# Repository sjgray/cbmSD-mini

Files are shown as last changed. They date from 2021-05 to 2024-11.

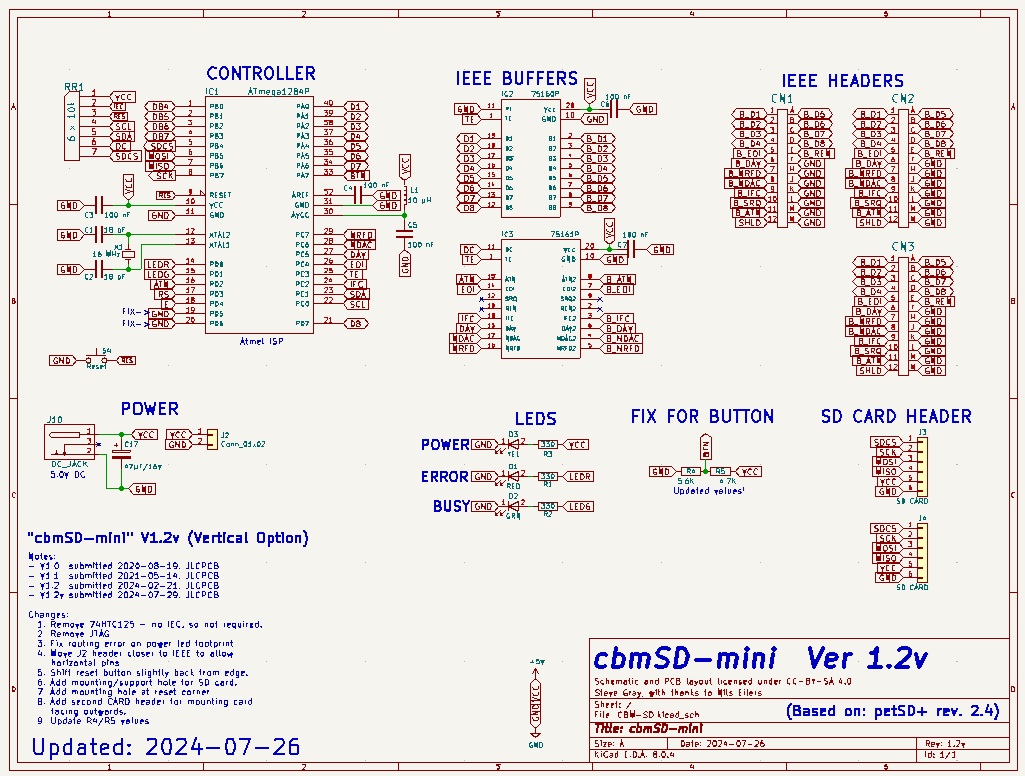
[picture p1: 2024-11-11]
v1.2v/Pics/schematic.jpg

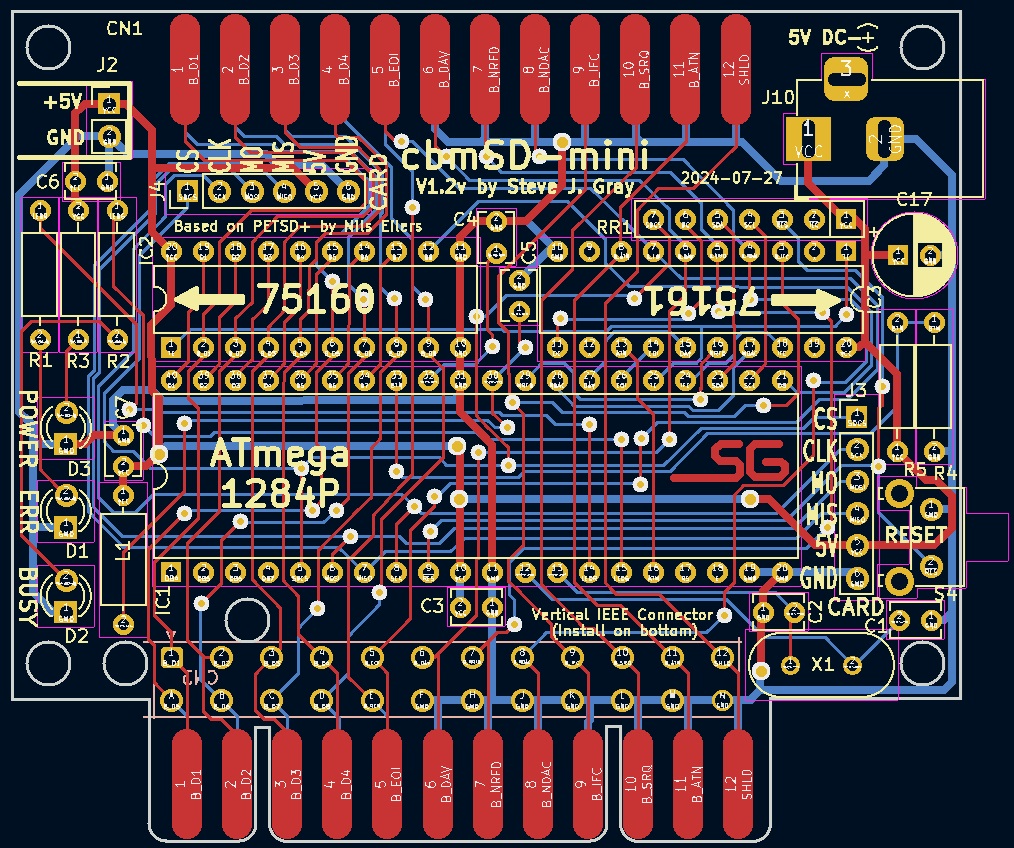
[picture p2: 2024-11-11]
v1.2v/Pics/routing.jpg

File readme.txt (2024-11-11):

cbmSD-mini - SD Card Drive for Commodore Computers with IEEE
============================================================

The goal of this project is to create a free open-source
disk drive solution that is easy to build using all
thru-hole parts plus the use of a common inexpensive SD
card module.

This device is based on the petSD+ v2.4 from Nils Eilers.
I have removed all the non-essential features and have
designed it to plug directly into the back of the computer.
No IEEE cables are required. However, it also has a
pass-thru to add additional drives if you need.

You will need a simple cassette port power plug or you can
power it with a standard 5V adapter with barrel jack.

Features
--------

- Direct plug into IEEE port
- Pass-thru IEEE port
- Power, Busy and Error lights
- SD module can be mounted on header or extended via wires.
- Reset switch.
- Two Power headers for input or output (to additional
  cbmSD-mini units).
- Mounting holes for future 3D case.

Project Page
------------

http://www.cbmsteve.ca/cbmsd/index.html

Status
------

 cbmSD      1.0:  Was the first version for prototyping. It supported IEEE and IEC
                  like the PETSD+. 
 cbmSD-mini 1.1:  Removed IEC port and AUX header. IEEE only for PET/CBM users.
                  Gerbers sent to JLCPCB on 2021-05-14.
 cbmSD-mini 1.2:  Fix trace short on LED. Remove 74125 which is not reqired
                  for IEEE. Update design for Kicad7.
                  Gerbers sent to JLCPCB on 2024-02-21.
 cmmSD-mini 1.2v  Add vertical mounting option.
                  Gerbers sent to JLCPCB on 2024-07-30.

Steve
2024-11-11

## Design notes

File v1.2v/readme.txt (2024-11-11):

cbmSD-mini - SD Card Drive for Commodore Computers with IEEE
============================================================

**NEW** Webpage: http://cbmsteve.ca/cbmsd/index.html

The goal of this project is to create a free open-source
disk drive solution that is easy to build using all
thru-hole parts plus the use of a common inexpensive SD
card module.

This device is based on the petSD+ v2.4 from Nils Eilers.
I have removed all the non-essential features and have
designed it to plug directly into the back of the computer.
No IEEE cables are required. However, it also has a
pass-thru to add additional drives if you need.

You will need a simple cassette port power plug or you can
power it with a standard 5V adapter with barrel jack.

Features
--------

- Direct plug into IEEE port
- Pass-thru IEEE port
- Power, Busy and Error lights
- SD module can be mounted on header or extended via wires.
- Reset switch.
- Two Power headers for input or output (to additional
  cbmSD-mini units.
- Mounting holes for future 3D case.
- Vertical mounting option

Status
------

 V1.0: Was the first version for prototyping. It had a few errors.       
 V1.1: Removed IEC port and AUX header. IEEE only for PET/CBM users.
       Gerbers sent to JLCPCB on 2021-05-14.
 V1.2: Fix trace short on LED. Remove 74125 which is not required
       for IEEE. Update design for Kicad7.
 V1.2v: No fundamental changes. Moved some parts to make way for
        vertical mounting option.

Steve
2024-02-21

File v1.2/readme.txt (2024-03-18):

cbmSD-mini - SD Card Drive for Commodore Computers with IEEE
============================================================

Webpage: http://www.6502.org/users/sjgray/projects/cbmsd/index.html

The goal of this project is to create a free open-source
disk drive solution that is easy to build using all
thru-hole parts plus the use of a common inexpensive SD
card module.

This device is based on the petSD+ v2.4 from Nils Eilers.
I have removed all the non-essential features and have
designed it to plug directly into the back of the computer.
No IEEE cables are required. However, it also has a
pass-thru to add additional drives if you need.

You will need a simple cassette port power plug or you can
power it with a standard 5V adapter with barrel jack.

Features
--------

- Direct plug into IEEE port
- Pass-thru IEEE port
- Power, Busy and Error lights
- SD module can be mounted on header or extended via wires.
- Reset switch.
- Two Power headers for input or output (to additional
  cbmSD-mini units.
- Mounting holes for future 3D case.

Status
------

 V1.0: Was the first version for prototyping. It had a few errors.       

 V1.1: Removed IEC port and AUX header. IEEE only for PET/CBM users.
       Gerbers sent to JLCPCB on 2021-05-14.
       Board built and verified working with one small fix.

 V1.2: Fix trace short on LED. Remove 74125 which is not reqired
       for IEEE. Update design for Kicad7.
       Gerbers sent to JLCPCB on 2024-02-21.
       Board built and verified working 2024-03-17

Steve
2024-03-18

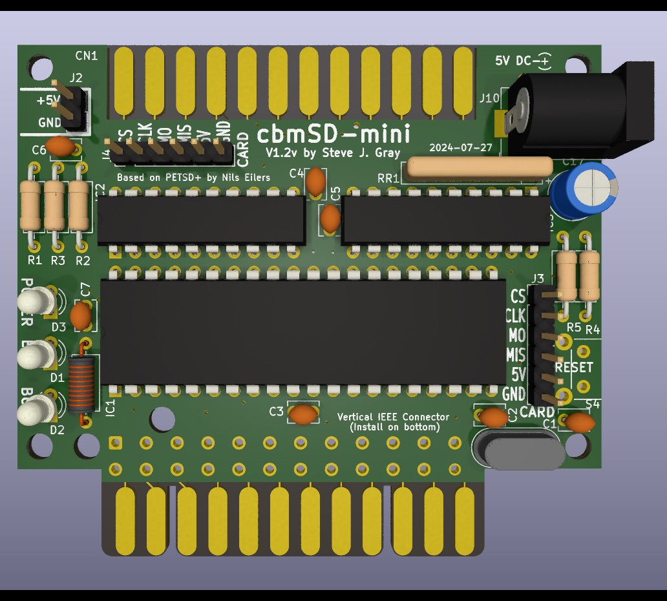
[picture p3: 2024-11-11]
v1.2v/Pics/render.jpg

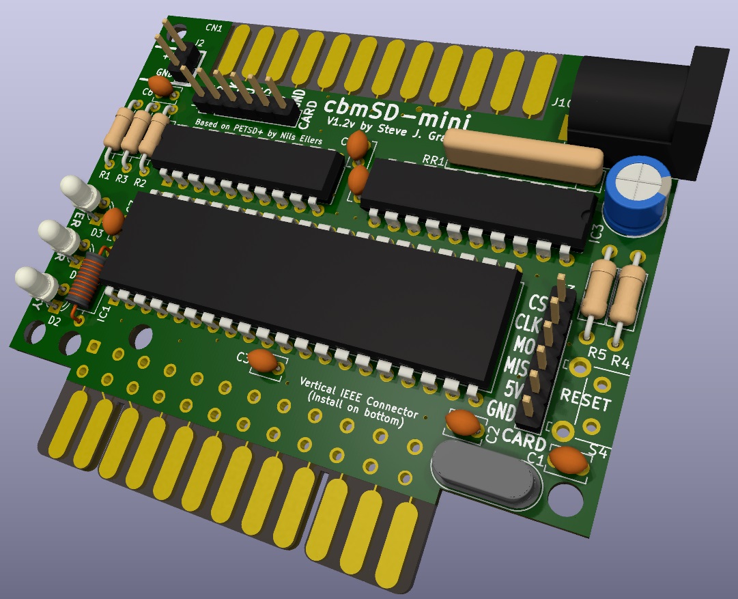
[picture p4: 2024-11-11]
v1.2v/Pics/render2.jpg

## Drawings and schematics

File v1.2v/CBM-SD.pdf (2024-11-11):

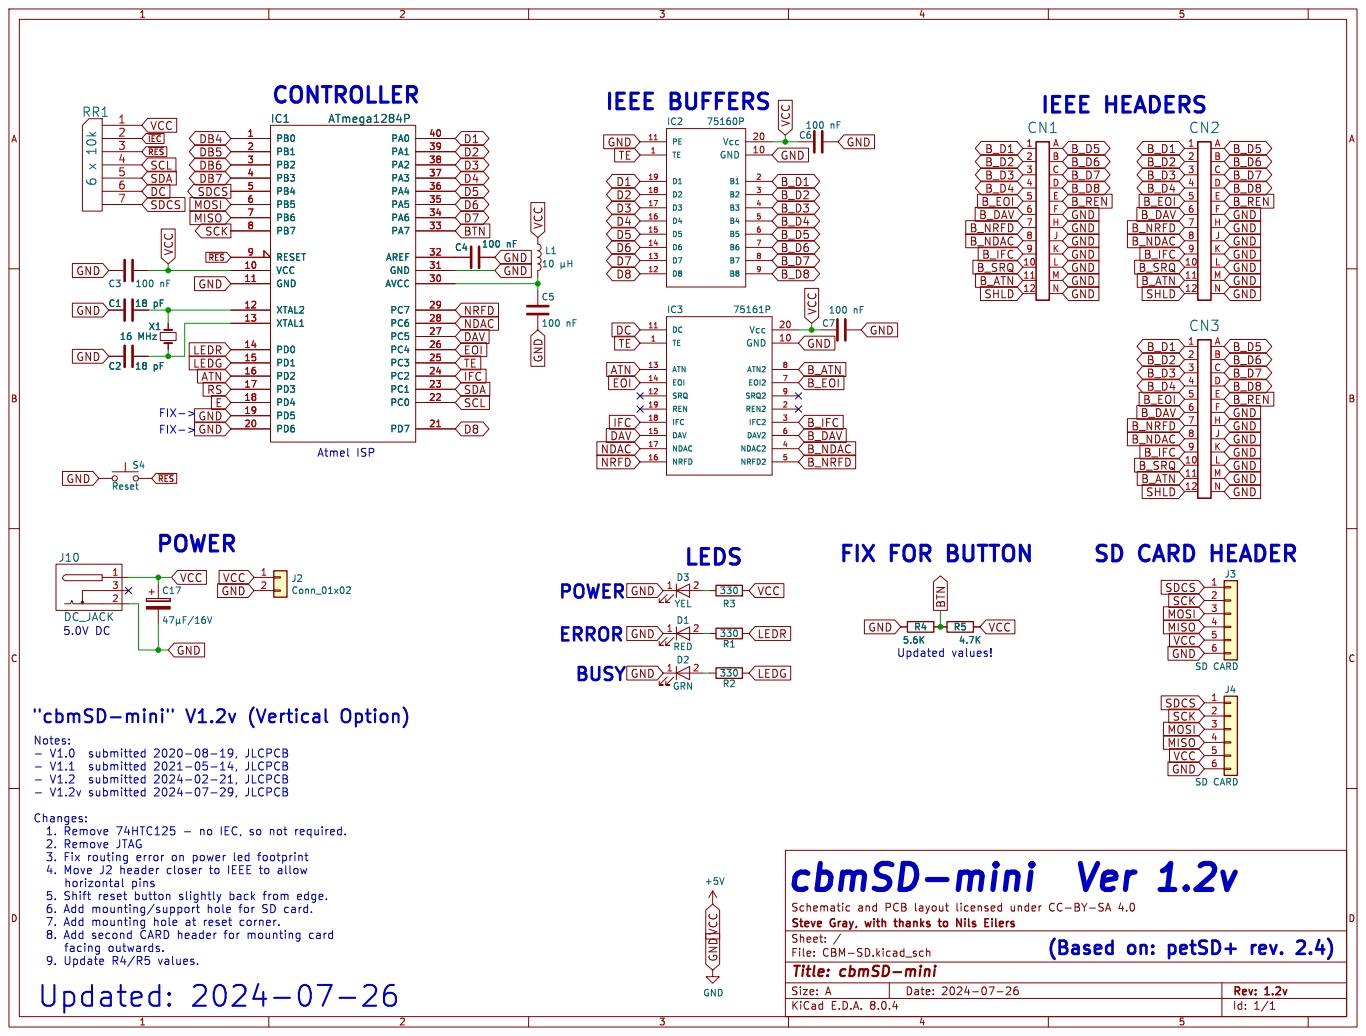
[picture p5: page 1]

Updated values! FIX FOR BUTTON

Changes: 1. Remove 74HTC125 - no IEC, so not required. 2. Remove JTAG

3. Fix routing error on power led footprint 4. Move J2 header closer to IEEE to allow

(Based on: petSD+ rev. 2.4)

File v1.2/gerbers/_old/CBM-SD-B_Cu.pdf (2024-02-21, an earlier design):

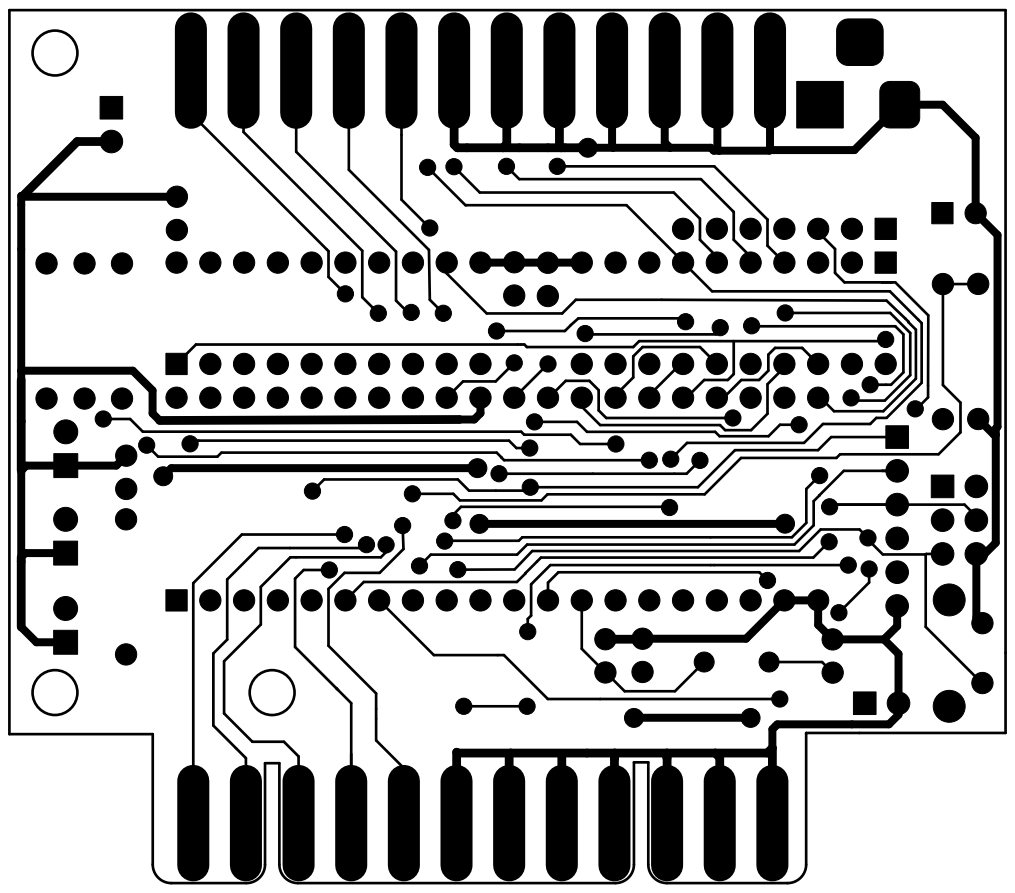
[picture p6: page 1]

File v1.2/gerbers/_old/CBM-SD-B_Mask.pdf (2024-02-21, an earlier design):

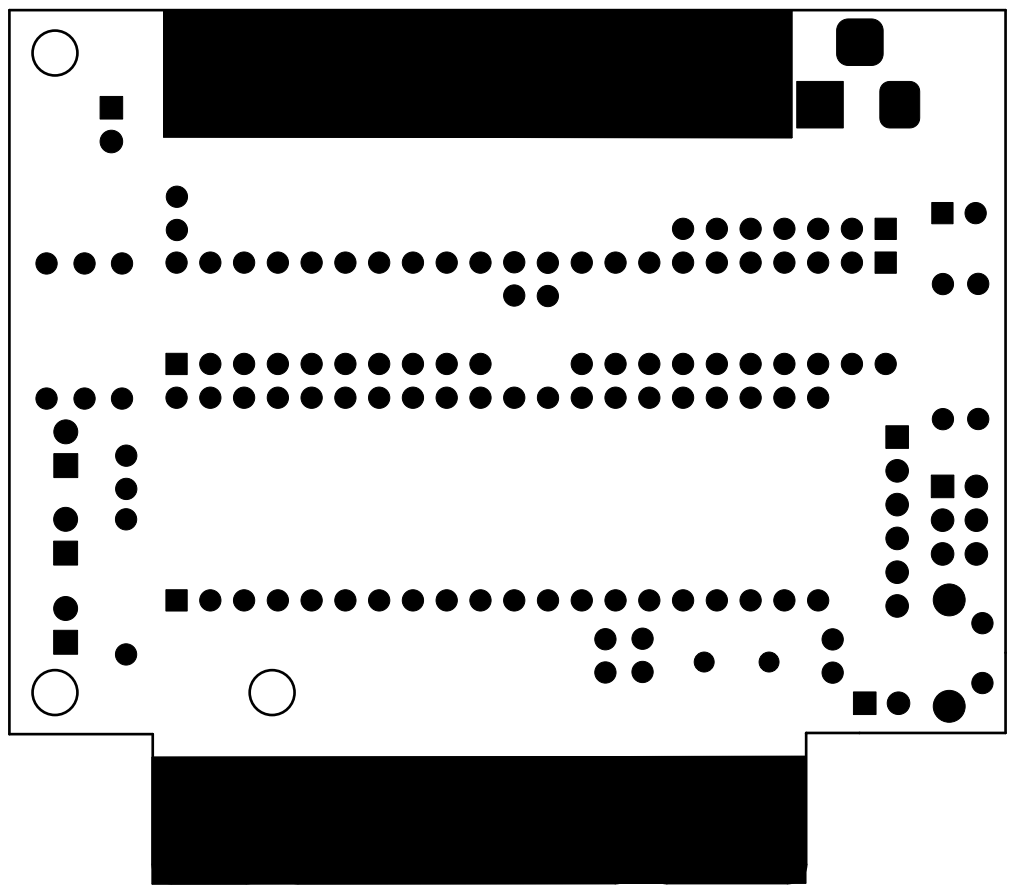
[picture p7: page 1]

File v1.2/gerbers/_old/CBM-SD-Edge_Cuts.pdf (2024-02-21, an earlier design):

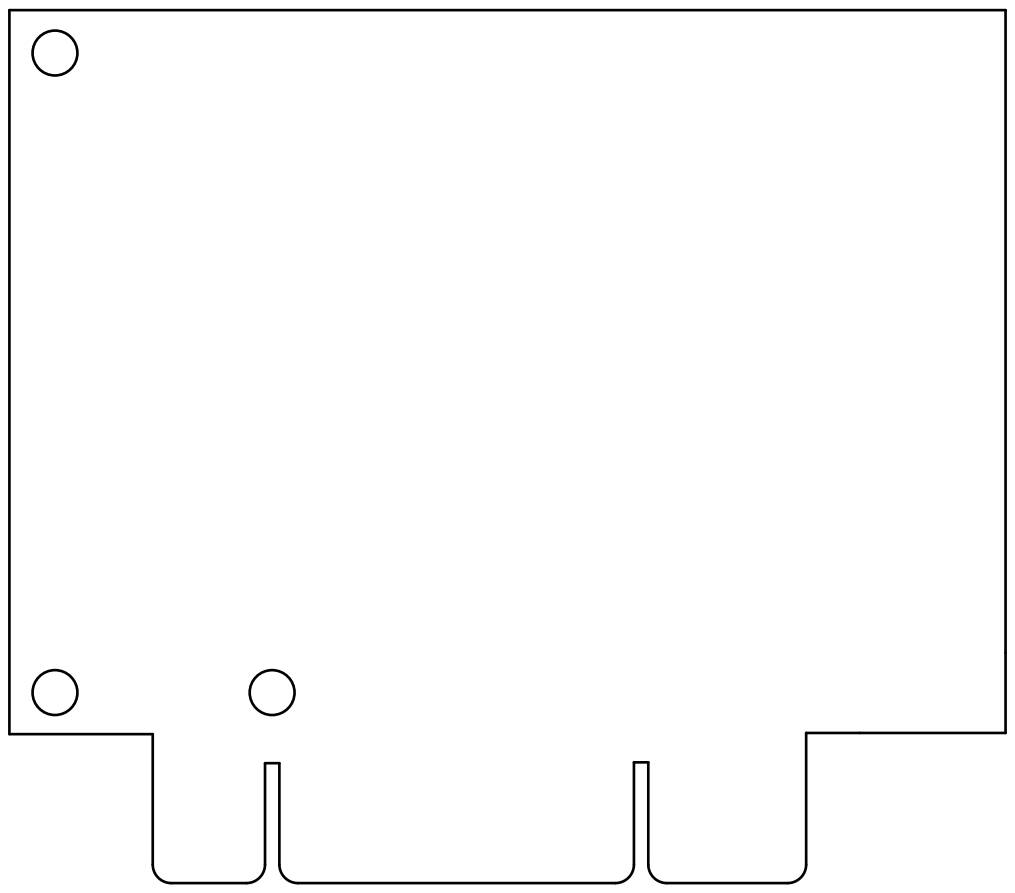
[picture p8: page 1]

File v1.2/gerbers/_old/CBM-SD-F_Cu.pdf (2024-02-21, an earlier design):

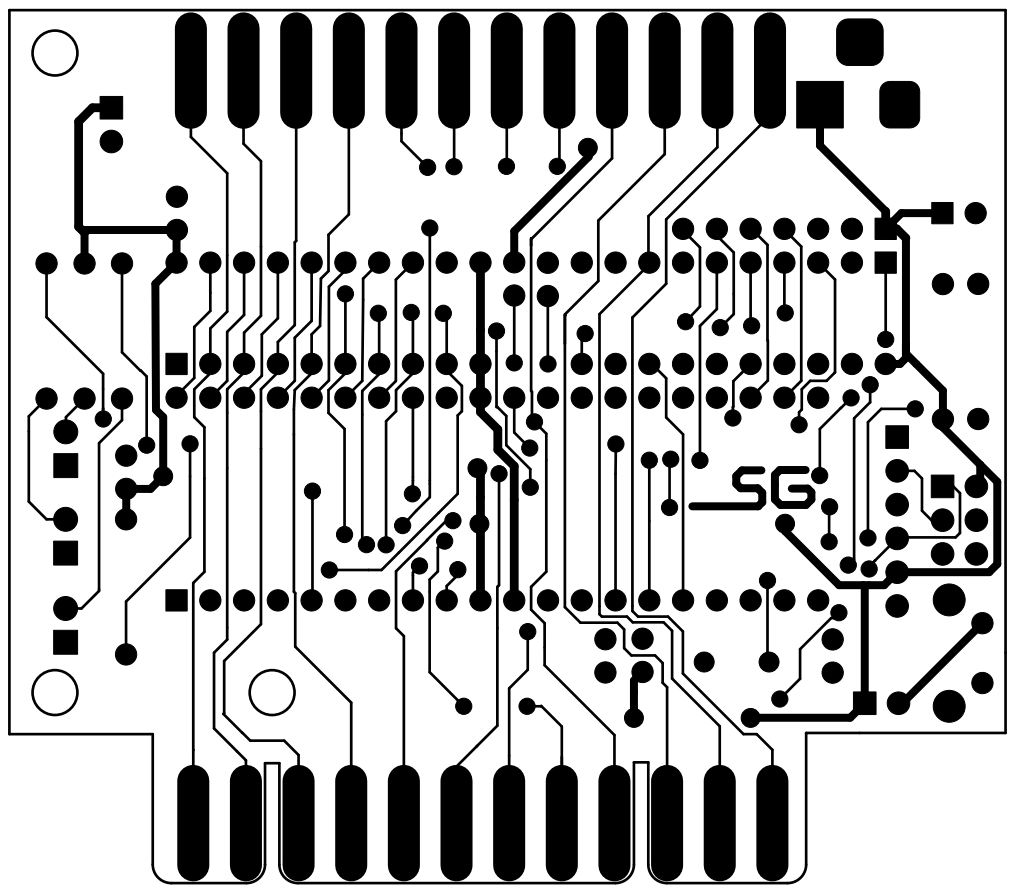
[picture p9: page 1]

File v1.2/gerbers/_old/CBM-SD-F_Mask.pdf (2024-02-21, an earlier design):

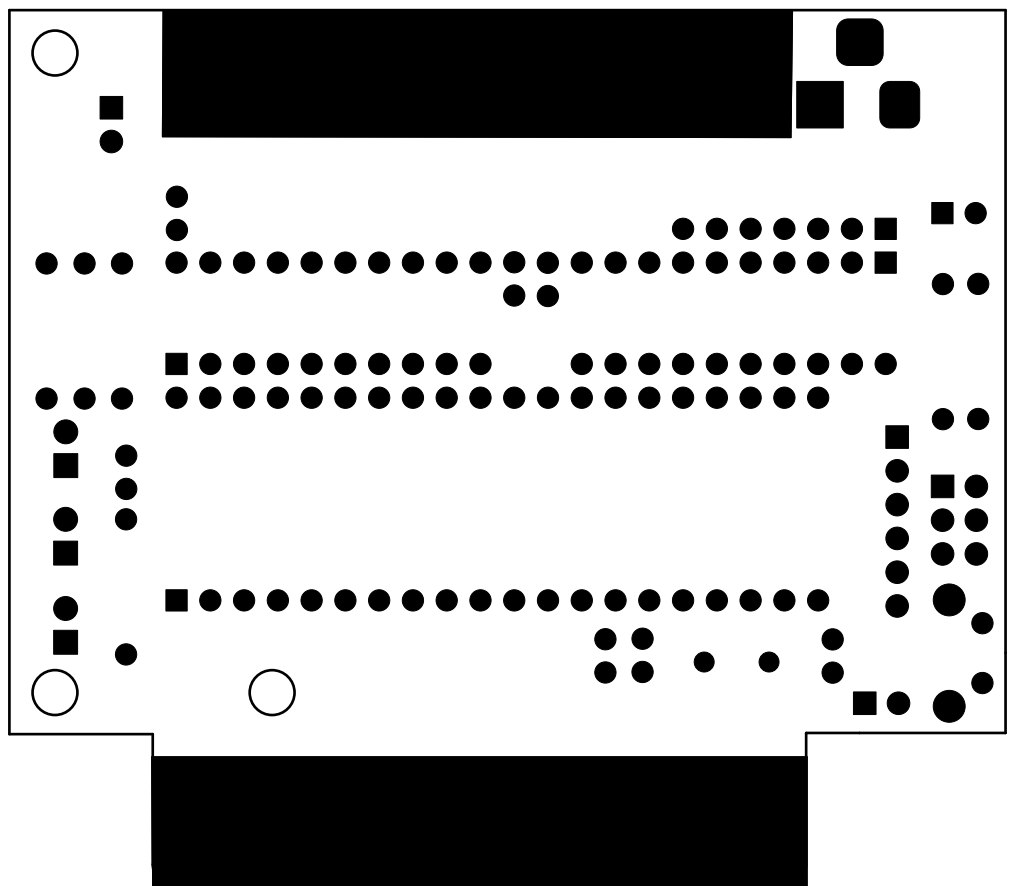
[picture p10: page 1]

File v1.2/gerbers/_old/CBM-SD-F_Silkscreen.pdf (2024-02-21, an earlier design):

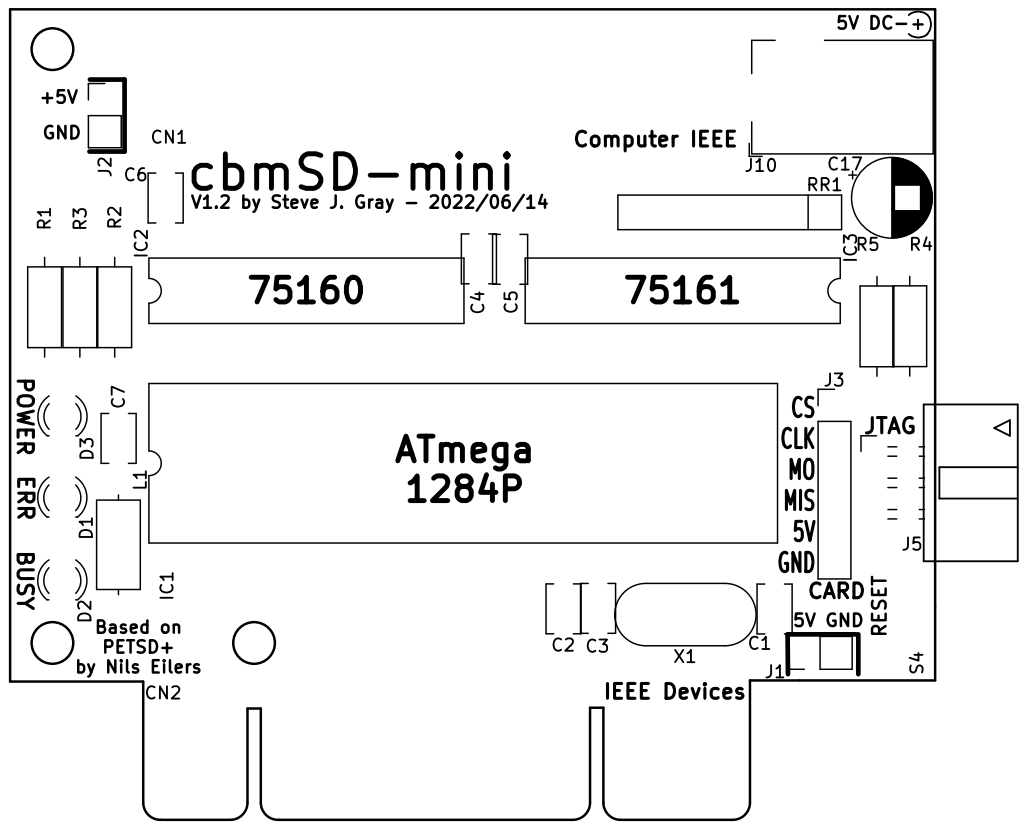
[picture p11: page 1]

V1.2 by Steve J. Gray - 2022/06/14 cbmSD-mini BUSY

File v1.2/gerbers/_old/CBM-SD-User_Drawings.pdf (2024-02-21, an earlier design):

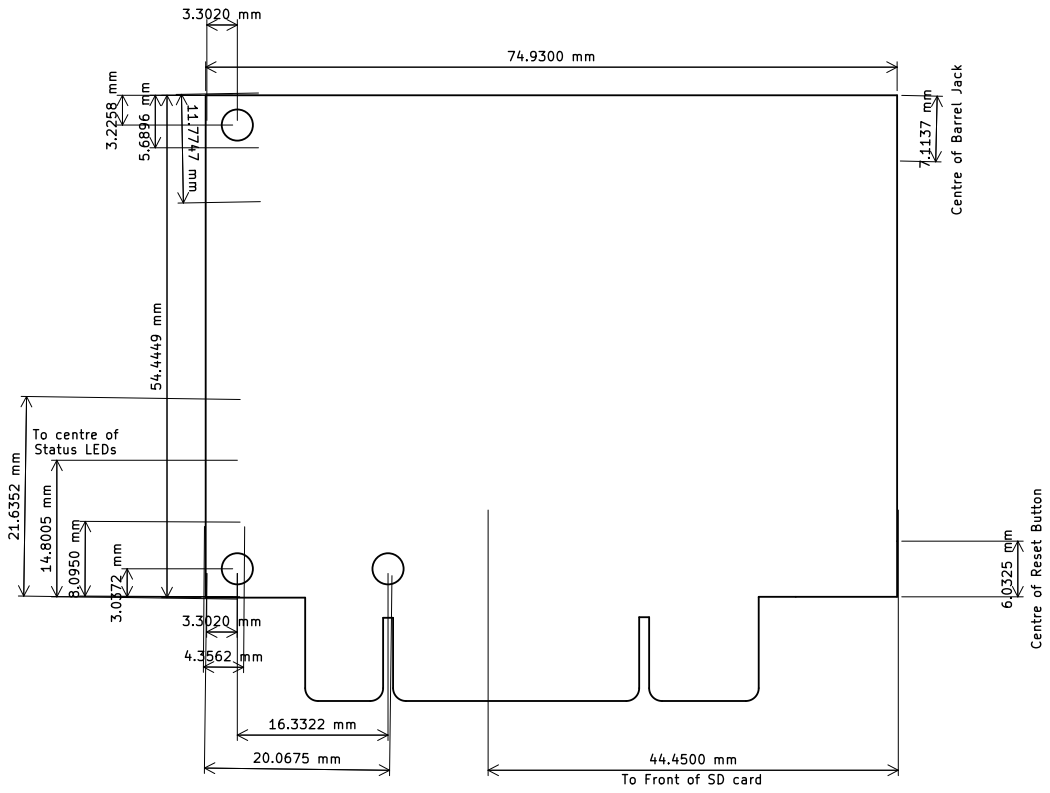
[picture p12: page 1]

To Front of SD card

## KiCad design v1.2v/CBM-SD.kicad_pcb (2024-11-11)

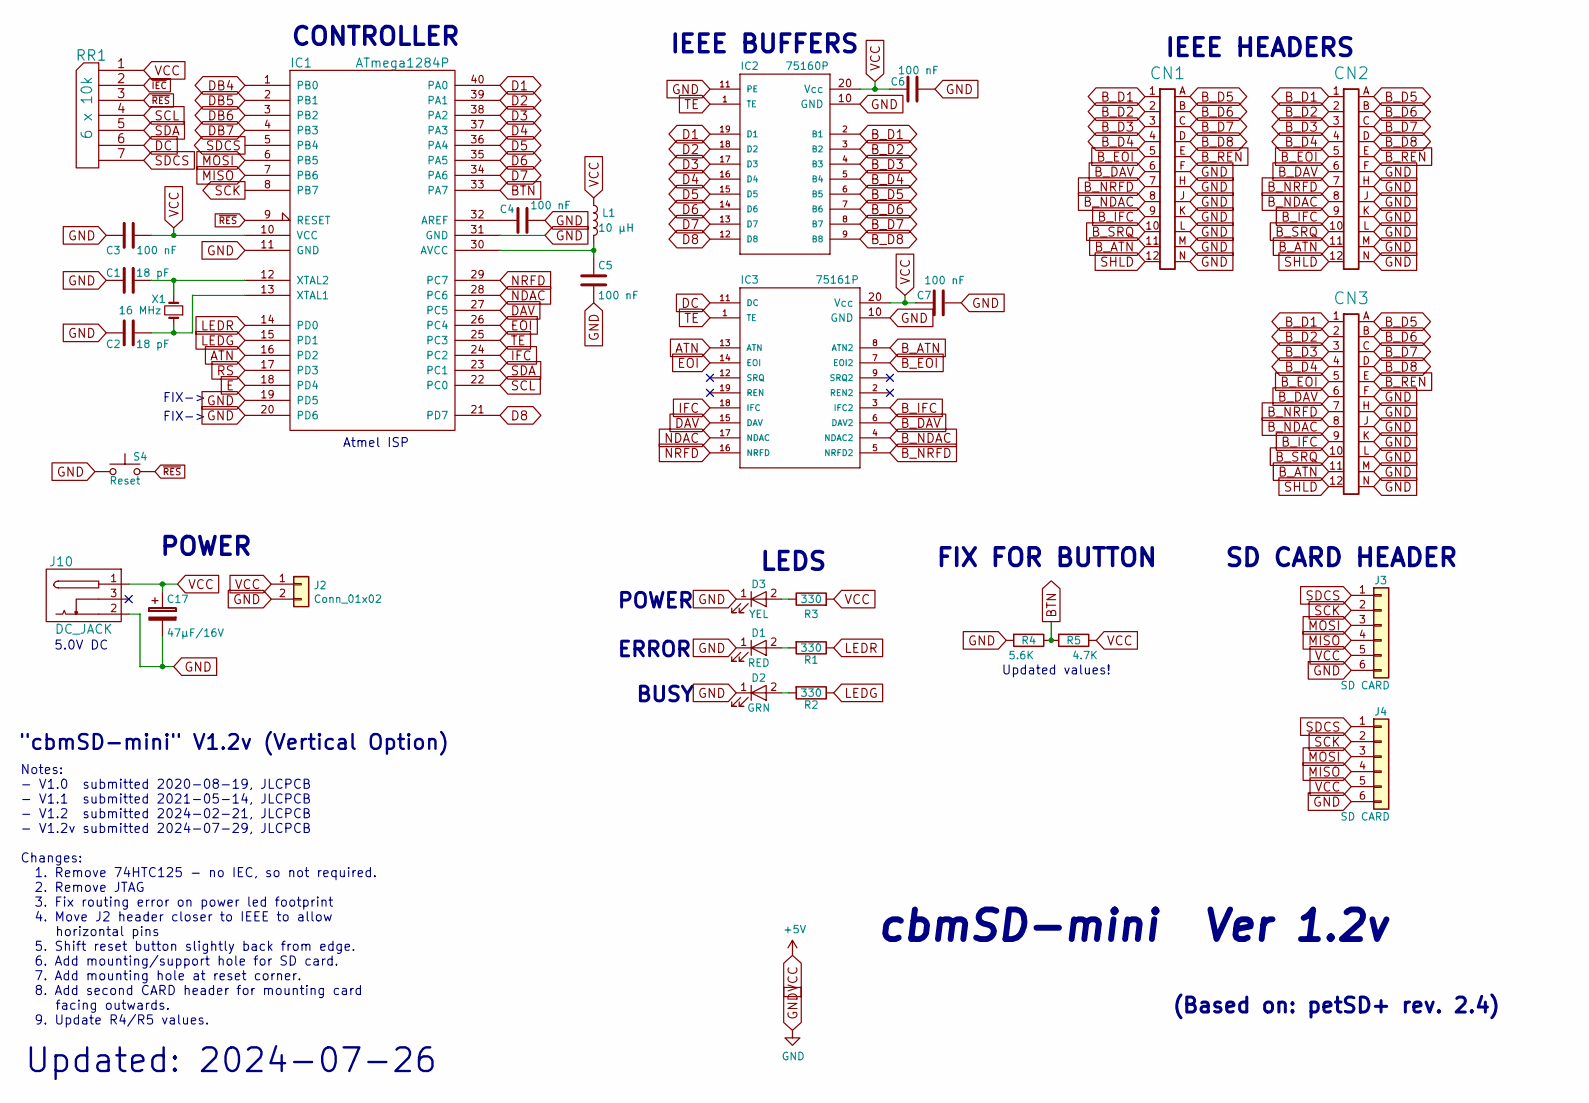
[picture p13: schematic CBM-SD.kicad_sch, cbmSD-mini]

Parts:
C1, C2: 18 pF; C_Disc_D3.8mm_W2.6mm_P2.50mm
C3, C4, C5, C6, C7: 100 nF; C_Disc_D3.8mm_W2.6mm_P2.50mm
C17: 47µF/16V; CP_Radial_D6.3mm_P2.50mm
CN1, CN2: EDGE_CON_02x12; EDGE_CON_24P
CN3: EDGE_CON_02x12; EDGE_02x12-VERTICAL_THT
D1: RED; LED_D3.0mm_Clear
D2: GRN; LED_D3.0mm_Clear
D3: YEL; LED_D3.0mm_Clear
IC1: ATmega1284P; DIP-40_W15.24mm
IC2: 75160P; DIP-20_W7.62mm
IC3: 75161P; DIP-20_W7.62mm
J2: Conn_01x02; PinHeader_1x02_P2.54mm_Vertical
J3, J4: SD CARD; PinHeader_1x06_P2.54mm_Vertical
J10: DC_JACK; BarrelJack_Horizontal
L1: 10 µH; L_Axial_L7.0mm_D3.3mm_P10.16mm_Horizontal_Fastron_MICC
R1, R2, R3: 330; R_Axial_DIN0207_L6.3mm_D2.5mm_P10.16mm_Horizontal
R4: 5.6K; R_Axial_DIN0207_L6.3mm_D2.5mm_P10.16mm_Horizontal
R5: 4.7K; R_Axial_DIN0207_L6.3mm_D2.5mm_P10.16mm_Horizontal
RR1: 6 x 10k; R_Array_SIP7
S4: Reset; SW_Tactile_SKHH_Angled
X1: 16 MHz; Crystal_HC49-4H_Vertical

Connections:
ATN: IC1.16 (PD2), IC3.13 (ATN)
BTN: IC1.33 (PA7), R4.1, R5.2
B_ATN: CN1.11, CN2.11, CN3.11, IC3.8 (ATN2)
B_D1: CN1.1, CN2.1, CN3.1, IC2.2 (B1)
B_D2: CN1.2, CN2.2, CN3.2, IC2.3 (B2)
B_D3: CN1.3, CN2.3, CN3.3, IC2.4 (B3)
B_D4: CN1.4, CN2.4, CN3.4, IC2.5 (B4)
B_D5: CN1.A, CN2.A, CN3.A, IC2.6 (B5)
B_D6: CN1.B, CN2.B, CN3.B, IC2.7 (B6)
B_D7: CN1.C, CN2.C, CN3.C, IC2.8 (B7)
B_D8: CN1.D, CN2.D, CN3.D, IC2.9 (B8)
B_DAV: CN1.6, CN2.6, CN3.6, IC3.6 (DAV2)
B_EOI: CN1.5, CN2.5, CN3.5, IC3.7 (EOI2)
B_IFC: CN1.9, CN2.9, CN3.9, IC3.3 (IFC2)
B_NDAC: CN1.8, CN2.8, CN3.8, IC3.4 (NDAC2)
B_NRFD: CN1.7, CN2.7, CN3.7, IC3.5 (NRFD2)
B_REN: CN1.E, CN2.E, CN3.E
B_SRQ: CN1.10, CN2.10, CN3.10
D1: IC1.40 (PA0), IC2.19 (D1)
D2: IC1.39 (PA1), IC2.18 (D2)
D3: IC1.38 (PA2), IC2.17 (D3)
D4: IC1.37 (PA3), IC2.16 (D4)
D5: IC1.36 (PA4), IC2.15 (D5)
D6: IC1.35 (PA5), IC2.14 (D6)
D7: IC1.34 (PA6), IC2.13 (D7)
D8: IC1.21 (PD7), IC2.12 (D8)
DAV: IC1.27 (PC5), IC3.15 (DAV)
DB4: IC1.1 (PB0)
DB5: IC1.2 (PB1)
DB6: IC1.3 (PB2)
DB7: IC1.4 (PB3)
DC: IC3.11 (DC), RR1.6
E: IC1.18 (PD4)
EOI: IC1.26 (PC4), IC3.14 (EOI)
GND: C1.1, C2.1, C3.1, C4.2, C5.2, C6.1, C7.1, C17.2, CN1.F, CN1.H, CN1.J, CN1.K, CN1.L, CN1.M, CN1.N, CN2.F, CN2.H, CN2.J, CN2.K, CN2.L, CN2.M, CN2.N, CN3.F, CN3.H, CN3.J, CN3.K, CN3.L, CN3.M, CN3.N, D1.1 (K), D2.1 (K), D3.1 (K), IC1.11 (GND), IC1.19 (PD5), IC1.20 (PD6), IC1.31 (GND), IC2.10 (GND), IC2.11 (PE), IC3.10 (GND), J2.2, J3.6, J4.6, J10.2, R4.2, S4.1
IFC: IC1.24 (PC2), IC3.18 (IFC)
LEDG: IC1.15 (PD1), R2.1
LEDR: IC1.14 (PD0), R1.1
MISO: IC1.7 (PB6), J3.4, J4.4
MOSI: IC1.6 (PB5), J3.3, J4.3
NDAC: IC1.28 (PC6), IC3.17 (NDAC)
NRFD: IC1.29 (PC7), IC3.16 (NRFD)
unnamed: D1.2 (A), R1.2
unnamed: D2.2 (A), R2.2
unnamed: D3.2 (A), R3.1
unnamed: C4.1, IC1.32 (AREF)
unnamed: C5.1, IC1.30 (AVCC), L1.2
unnamed: C2.2, IC1.13 (XTAL1), X1.1
unnamed: C1.2, IC1.12 (XTAL2), X1.2
RS: IC1.17 (PD3)
SCK: IC1.8 (PB7), J3.2, J4.2
SCL: IC1.22 (PC0), RR1.4
SDA: IC1.23 (PC1), RR1.5
SDCS: IC1.5 (PB4), J3.1, J4.1, RR1.7
SHLD: CN1.12, CN2.12, CN3.12
TE: IC1.25 (PC3), IC2.1 (TE), IC3.1 (TE)
VCC: C3.2, C6.2, C7.2, C17.1, IC1.10 (VCC), IC2.20 (Vcc), IC3.20 (Vcc), J2.1, J3.5, J4.5, J10.1, L1.1, R3.2, R5.1, RR1.1 (COM)
~IEC: RR1.2
~RES: IC1.9 (RESET), RR1.3, S4.2

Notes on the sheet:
Updated values!
5.0V DC
BUSY
Notes: - V1.0 submitted 2020-08-19, JLCPCB - V1.1 submitted 2021-05-14, JLCPCB - V1.2 submitted 2024-02-21, JLCPCB - V1.2v submitted 2024-07-29, JLCPCB Changes: 1. Remove 74HTC125 - no IEC, so not required. 2. Remove JTAG 3. Fix routing error on power led footprint 4. Move J2 header closer to IEEE 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
Atmel ISP
"cbmSD-mini" V1.2v (Vertical Option)
FIX FOR BUTTON
SD CARD HEADER
cbmSD-mini Ver 1.2v
CONTROLLER
IEEE HEADERS
(Based on: petSD+ rev. 2.4)
FIX->
POWER
LEDS
ERROR
Updated: 2024-07-26
IEEE BUFFERS

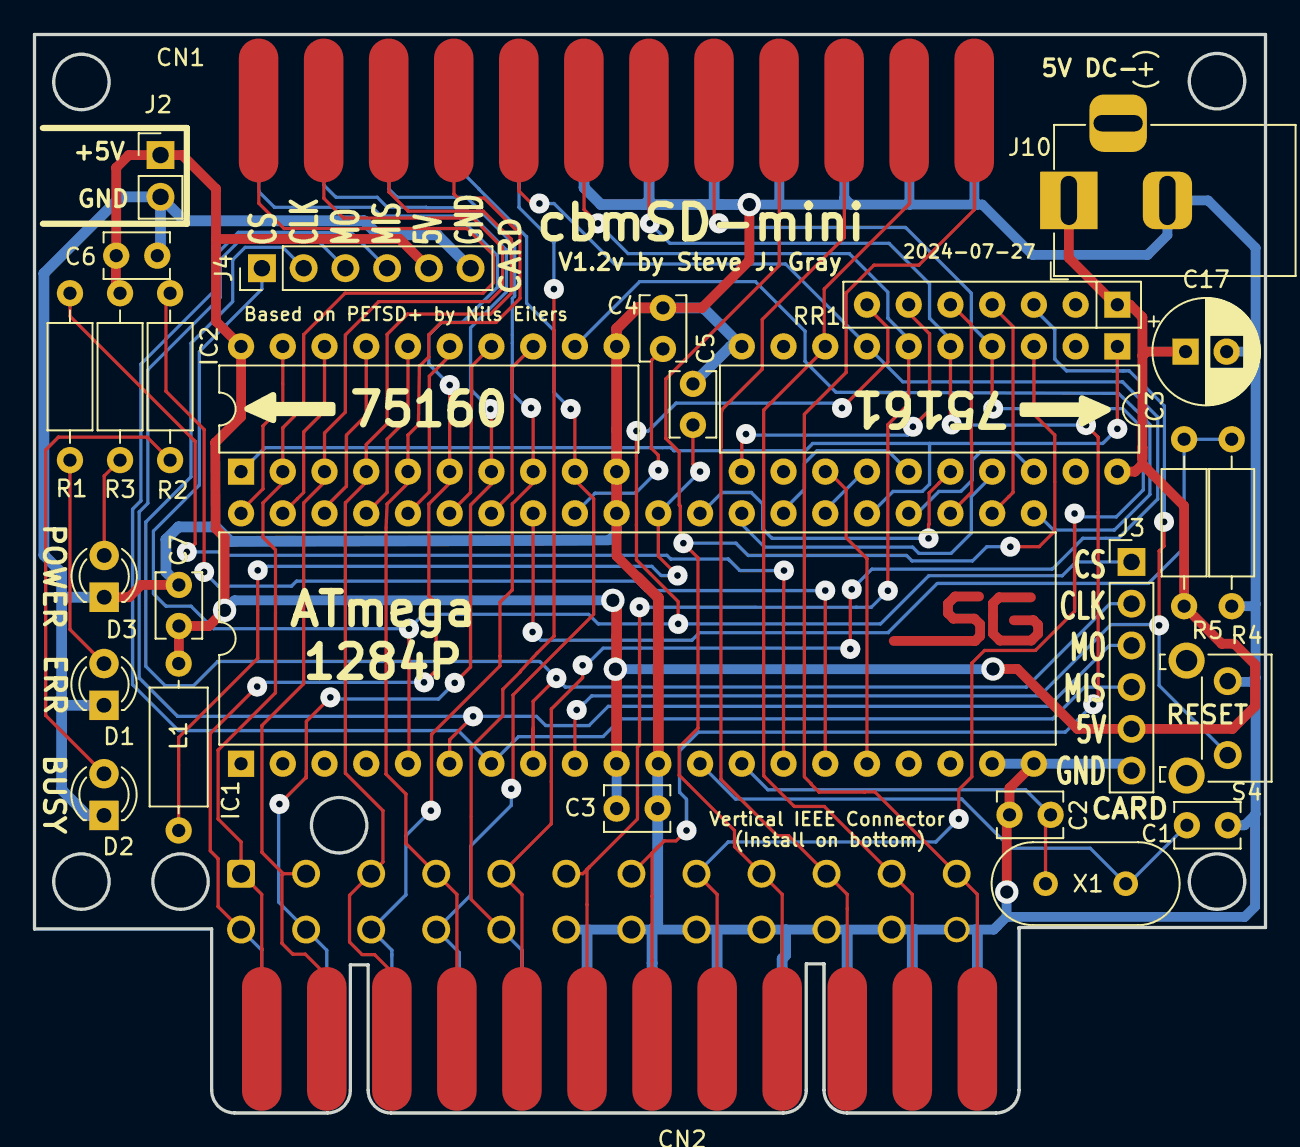
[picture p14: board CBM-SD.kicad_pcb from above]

Board: 2 copper layers, 74.9 x 65.6 mm, 30 parts (1 on the bottom side), 52 nets.

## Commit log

2021-05-15 V1.1 Initial commit
    Initial commit. Boards have been ordered but not verified. See webpage
    for info.
    [CBM-SD.kicad_pcb, CBM-SD.sch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]
2024-02-21 cbmSD-mini V1.2 Release
    Released V1.2 with Gerbers. This is mostly a cleanup of V1.1 with 74125 removed. Updated for Kicad7. Version 1.1 and 1.2 are in separate directories now.
    [CBM-SD-B_Cu.gbr, CBM-SD-B_Mask.gbr, CBM-SD-Edge_Cuts.gbr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]
2024-03-18 V1.2 verified
    Board built and is working correctly!
2024-06-01 Add Interactive BOM
    Add interactive BOM
2024-11-11 Version 1.2v Release
    Moved a few components and added vertical mounting option.
    [CBM-SD-B_Cu.gbr, CBM-SD-B_Mask.gbr, CBM-SD-B_Silkscreen.gbr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]
2024-11-11 Update readme
    Add 1.2v

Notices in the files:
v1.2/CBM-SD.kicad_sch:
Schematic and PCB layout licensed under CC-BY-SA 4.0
